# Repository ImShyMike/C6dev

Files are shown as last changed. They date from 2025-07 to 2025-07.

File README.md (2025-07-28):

# C6dev

A tiny and low power dev board for the ESP32-C6 with 10 GPIO pins, microSD card slot, 64Mbit (8MB) of Quad SPI Flash, USB C 2.0, a step-down converter for efficiency, 2.4 GHz ceramic chip antenna and very cool silkscreen. All pins are labeled with their number, actual GPIO and even other functions.

---

I've been wanting to make a devboard for a while now so i decided to make one with a RISC-V, low power MCU while breaking out a bunch of useful stuff while still keeping an acceptable amount of GPIO.

It was quite a lot harder than I expected with all the datasheet searching and looking up everything to make sure it works but atleast the routing was quite fun.

---

| PCB front | PCB back |
|:---:|:---:|
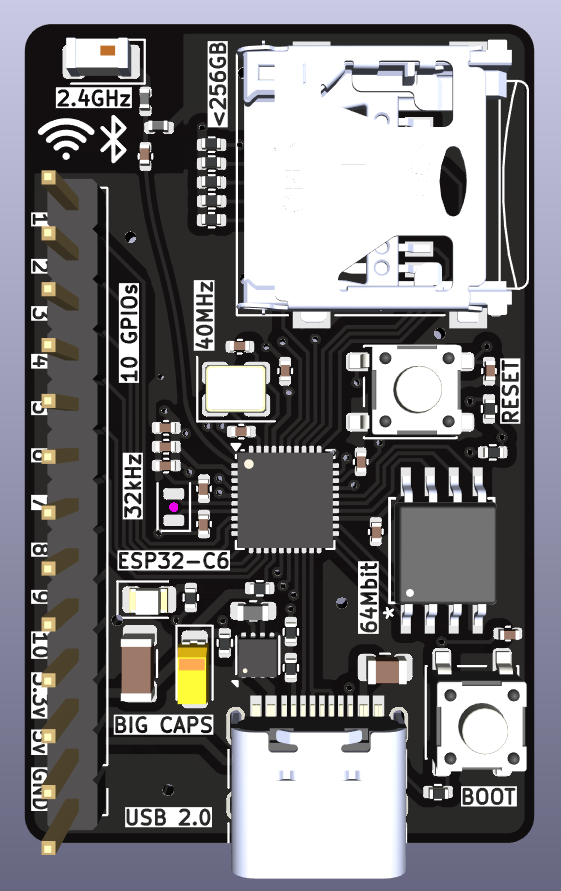
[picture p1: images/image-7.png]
PCB front
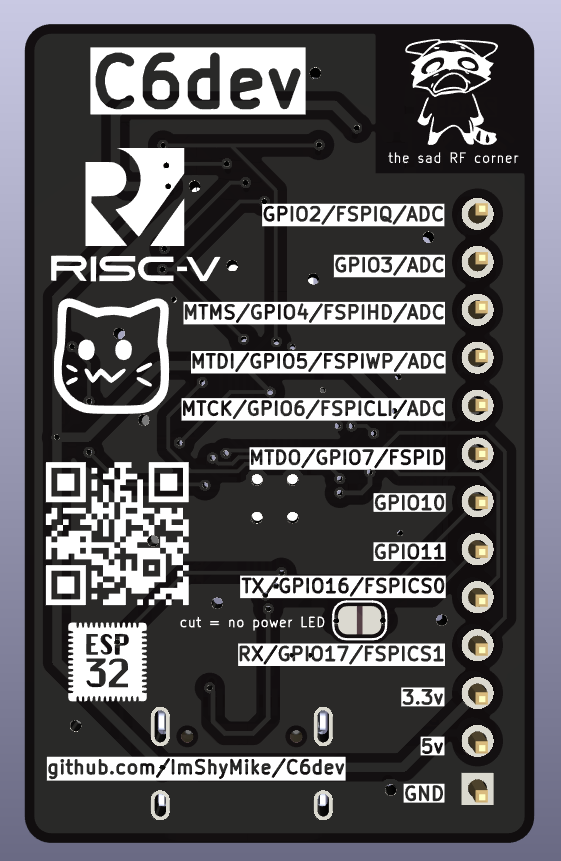
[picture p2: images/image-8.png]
PCB back
|  |  |

---

## PCB

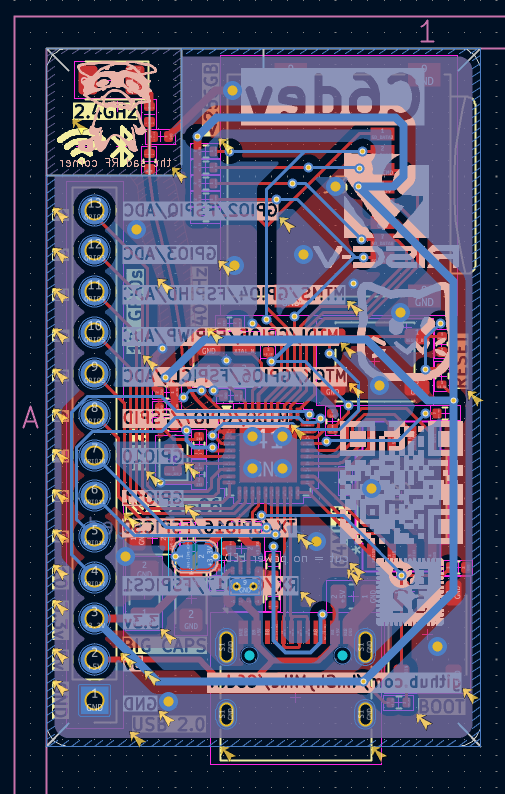
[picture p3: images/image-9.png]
PCB


---

## BOM

| Item | Quantity | Price (USD) |
|:----:|:---:|:---:|
| PCB  | 1  | $77 |

---

## 3D Model

[STL (renders on GitHub)](PCB/devboard/devboard.stl)

[STEP](PCB/devboard/devboard.stl)

[WRL (best)](PCB/devboard/devboard.wrl)

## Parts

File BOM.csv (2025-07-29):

Item | Quantity | Price (USD)
PCB | 1 | 77

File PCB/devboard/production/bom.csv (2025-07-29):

Designator | Footprint | Quantity | Value | LCSC Part #
AE1 | Johanson_2450AT18x100_2400-2500Mhz | 1 | Antenna
C1, C10, C11, C12, C15, C16, C8, C9 | 0402 | 8 | 100nF
C13 | 0402 | 1 | 1.2pF
C14 | CP_EIA-3216-18_Kemet-A | 1 | 100uF
C2, C3 | 0402 | 2 | 12pF
C4, C5 | 0402 | 2 | 6.8pF
C6 | 0805 | 1 | 10uF
C7 | 1206 | 1 | 22uF
D1 | 0805 | 1 | LED
J1 | PinHeader_1x13_P2.54mm_Vertical | 1 | Conn_01x13_Pin
J3 | microSD_HC_Wuerth_693072010801 | 1 | Micro_SD_Card
J4 | USB_C_Receptacle_HRO_TYPE-C-31-M-12 | 1 | USB_C_Receptacle_USB2.0_14P
JP1 | SolderJumper-2_P1.3mm_Open_RoundedPad1.0x1.5mm | 1 | Jumper_2_Bridged
L1 | 0603 | 1 | 2.2uH
L2 | 0402 | 1 | 3.3nH
L3 | 0402 | 1 | 2.7nH
R1, R10, R11, R12, R13, R2, R3, R4, R8, R9 | 0402 | 10 | 10k
R5, R6 | 0402 | 2 | 5.1kΩ
R7 | 0402 | 1 | 100k
SW1, SW2 | SW_SPST_PTS647_Sx38 | 2 | SW_Push
U1 | QFN-40-1EP_5x5mm_P0.4mm_EP3.6x3.6mm | 1 | ESP32-C6
U2 | WSON-8-1EP_2x2mm_P0.5mm_EP0.9x1.6mm_ThermalVias | 1 | TPS62172DSG
U3 | SOIC-8_5P28X5P28_WIN | 1 | W25Q64JVSSIQ
Y1 | Crystal_SMD_3225-4Pin_3.2x2.5mm | 1 | C521661
Y3 | Crystal_SMD_2012-2Pin_2.0x1.2mm | 1 | Crystal

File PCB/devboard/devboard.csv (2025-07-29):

Id | Designator | Footprint | Quantity | Designation | Supplier and ref
1 | U3 | SOIC-8_5P28X5P28_WIN | 1 | W25Q64JVSSIQ
2 | C15,C8,C11,C16,C9,C12,C1,C10 | C_0402_1005Metric | 8 | 100nF
3 | C14 | CP_EIA-3216-18_Kemet-A | 1 | 100uF
4 | R5,R6 | R_0402_1005Metric | 2 | 5.1kΩ
5 | C4,C5 | C_0402_1005Metric | 2 | 6.8pF
6 | C6 | C_0805_2012Metric | 1 | 10uF
7 | R8,R13,R9,R3,R4,R11,R10,R12,R1,R2 | R_0402_1005Metric | 10 | 10k
8 | SW1,SW2 | SW_SPST_PTS647_Sx38 | 2 | SW_Push
9 | J3 | microSD_HC_Wuerth_693072010801 | 1 | Micro_SD_Card
10 | L1 | L_0603_1608Metric | 1 | 2.2uH
11 | AE1 | Johanson_2450AT18x100_2400-2500Mhz | 1 | Antenna
12 | J1 | PinHeader_1x13_P2.54mm_Vertical | 1 | Conn_01x13_Pin
13 | L2 | L_0402_1005Metric | 1 | 3.3nH
14 | C7 | C_1206_3216Metric | 1 | 22uF
15 | U1 | QFN-40-1EP_5x5mm_P0.4mm_EP3.6x3.6mm | 1 | ESP32-C6
16 | C2,C3 | C_0402_1005Metric | 2 | 12pF
17 | L3 | L_0402_1005Metric | 1 | 2.7nH
18 | Y1 | Crystal_SMD_3225-4Pin_3.2x2.5mm | 1 | C521661
19 | D1 | LED_0805_2012Metric | 1 | LED
20 | U2 | WSON-8-1EP_2x2mm_P0.5mm_EP0.9x1.6mm_ThermalVias | 1 | TPS62172DSG
21 | Y3 | Crystal_SMD_2012-2Pin_2.0x1.2mm | 1 | Crystal
22 | J4 | USB_C_Receptacle_HRO_TYPE-C-31-M-12 | 1 | USB_C_Receptacle_USB2.0_14P
23 | C13 | C_0402_1005Metric | 1 | 1.2pF
24 | R7 | R_0402_1005Metric | 1 | 100k
25 | JP1 | SolderJumper-2_P1.3mm_Open_RoundedPad1.0x1.5mm | 1 | Jumper_2_Bridged

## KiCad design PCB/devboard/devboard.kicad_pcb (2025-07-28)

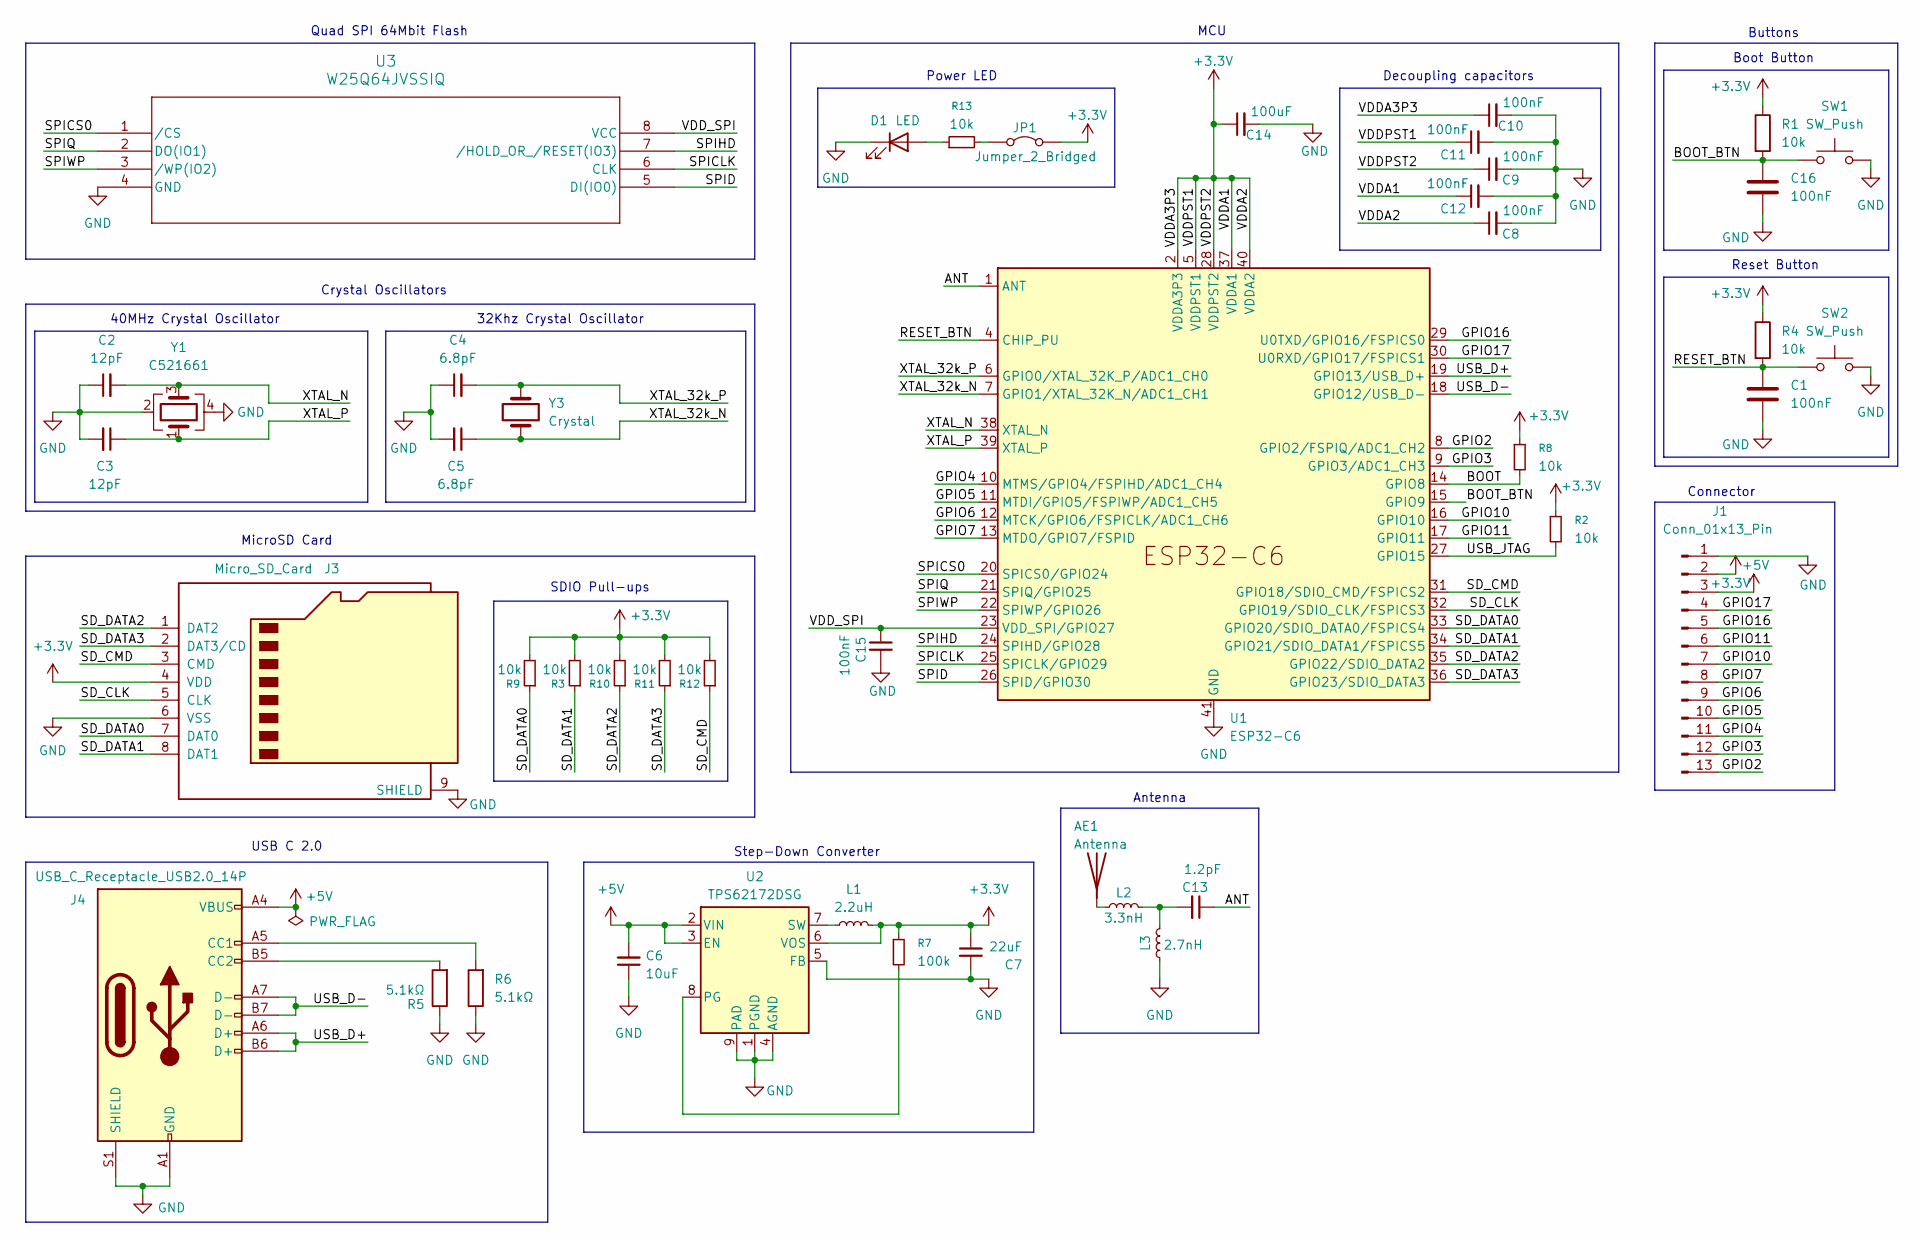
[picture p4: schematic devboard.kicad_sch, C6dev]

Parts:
AE1: Antenna; Johanson_2450AT18x100_2400-2500Mhz
C1, C8, C9, C10, C11, C12, C15, C16: 100nF; C_0402_1005Metric
C2, C3: 12pF; C_0402_1005Metric
C4, C5: 6.8pF; C_0402_1005Metric
C6: 10uF; C_0805_2012Metric
C7: 22uF; C_1206_3216Metric
C13: 1.2pF; C_0402_1005Metric
C14: 100uF; CP_EIA-3216-18_Kemet-A
D1: LED; LED_0805_2012Metric
J1: Conn_01x13_Pin; PinHeader_1x13_P2.54mm_Vertical
J3: Micro_SD_Card; microSD_HC_Wuerth_693072010801
J4: USB_C_Receptacle_USB2.0_14P; USB_C_Receptacle_HRO_TYPE-C-31-M-12
JP1: Jumper_2_Bridged; SolderJumper-2_P1.3mm_Open_RoundedPad1.0x1.5mm
L1: 2.2uH; L_0603_1608Metric
L2: 3.3nH; L_0402_1005Metric
L3: 2.7nH; L_0402_1005Metric
R1, R2, R3, R4, R8, R9, R10, R11, R12, R13: 10k; R_0402_1005Metric
R5, R6: 5.1kΩ; R_0402_1005Metric
R7: 100k; R_0402_1005Metric
SW1, SW2: SW_Push; SW_SPST_PTS647_Sx38
U1: ESP32-C6; QFN-40-1EP_5x5mm_P0.4mm_EP3.6x3.6mm
U2: TPS62172DSG; WSON-8-1EP_2x2mm_P0.5mm_EP0.9x1.6mm_ThermalVias
U3: W25Q64JVSSIQ; SOIC-8_5P28X5P28_WIN
Y1: C521661; Crystal_SMD_3225-4Pin_3.2x2.5mm
Y3: Crystal; Crystal_SMD_2012-2Pin_2.0x1.2mm

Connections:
+3.3V: C7.1, C8.1, C9.1, C10.1, C11.1, C12.1, C14.1, J1.3, J3.4 (VDD), JP1.2 (B), L1.2, R1.1, R2.1, R3.2, R4.1, R7.1, R8.1, R9.2, R10.2, R11.2, R12.2, U1.2 (VDDA3P3), U1.3 (VDDA3P3), U1.5 (VDDPST1), U1.28 (VDDPST2), U1.37 (VDDA1), U1.40 (VDDA2), U2.6 (VOS)
+5V: C6.2, J1.2, J4.A4 (VBUS), J4.A9 (VBUS), J4.B4 (VBUS), J4.B9 (VBUS), U2.2 (VIN), U2.3 (EN)
/ANT: C13.1, U1.1 (ANT)
/BOOT: R8.2, U1.14 (GPIO8)
/BOOT_BTN: C16.1, R1.2, SW1.1, U1.15 (GPIO9)
/GPIO2: J1.13, U1.8 (GPIO2/FSPIQ/ADC1_CH2)
/GPIO3: J1.12, U1.9 (GPIO3/ADC1_CH3)
/GPIO4: J1.11, U1.10 (MTMS/GPIO4/FSPIHD/ADC1_CH4)
/GPIO5: J1.10, U1.11 (MTDI/GPIO5/FSPIWP/ADC1_CH5)
/GPIO6: J1.9, U1.12 (MTCK/GPIO6/FSPICLK/ADC1_CH6)
/GPIO7: J1.8, U1.13 (MTDO/GPIO7/FSPID)
/GPIO10: J1.7, U1.16 (GPIO10)
/GPIO11: J1.6, U1.17 (GPIO11)
/GPIO16: J1.5, U1.29 (U0TXD/GPIO16/FSPICS0)
/GPIO17: J1.4, U1.30 (U0RXD/GPIO17/FSPICS1)
/RESET_BTN: C1.1, R4.2, SW2.1, U1.4 (CHIP_PU)
/SD_CLK: J3.5 (CLK), U1.32 (GPIO19/SDIO_CLK/FSPICS3)
/SD_CMD: J3.3 (CMD), R12.1, U1.31 (GPIO18/SDIO_CMD/FSPICS2)
/SD_DATA0: J3.7 (DAT0), R9.1, U1.33 (GPIO20/SDIO_DATA0/FSPICS4)
/SD_DATA1: J3.8 (DAT1), R3.1, U1.34 (GPIO21/SDIO_DATA1/FSPICS5)
/SD_DATA2: J3.1 (DAT2), R10.1, U1.35 (GPIO22/SDIO_DATA2)
/SD_DATA3: J3.2 (DAT3/CD), R11.1, U1.36 (GPIO23/SDIO_DATA3)
/SPICLK: U1.25 (SPICLK/GPIO29), U3.6 (CLK)
/SPICS0: U1.20 (SPICS0/GPIO24), U3.1 (/CS)
/SPID: U1.26 (SPID/GPIO30), U3.5 (DI(IO0))
/SPIHD: U1.24 (SPIHD/GPIO28), U3.7 (/HOLD_OR_/RESET(IO3))
/SPIQ: U1.21 (SPIQ/GPIO25), U3.2 (DO(IO1))
/SPIWP: U1.22 (SPIWP/GPIO26), U3.3 (/WP(IO2))
/USB_D+: J4.A6 (D+), J4.B6 (D+), U1.19 (GPIO13/USB_D+)
/USB_D-: J4.A7 (D-), J4.B7 (D-), U1.18 (GPIO12/USB_D-)
/USB_JTAG: R2.2, U1.27 (GPIO15)
/VDD_SPI: C15.1, U1.23 (VDD_SPI/GPIO27), U3.8 (VCC)
/XTAL_32k_N: C5.1, U1.7 (GPIO1/XTAL_32K_N/ADC1_CH1), Y3.1
/XTAL_32k_P: C4.2, U1.6 (GPIO0/XTAL_32K_P/ADC1_CH0), Y3.2
/XTAL_N: C2.2, U1.38 (XTAL_N), Y1.3
/XTAL_P: C3.1, U1.39 (XTAL_P), Y1.1
GND: C1.2, C2.1, C3.2, C4.1, C5.2, C6.1, C7.2, C8.2, C9.2, C10.2, C11.2, C12.2, C14.2, C15.2, C16.2, D1.1 (K), J1.1, J3.6 (VSS), J3.9 (SHIELD), J4.A1 (GND), J4.A12 (GND), J4.B1 (GND), J4.B12 (GND), J4.S1 (SHIELD), L3.1, R5.1, R6.1, SW1.2, SW2.2, U1.41 (GND), U2.1 (PGND), U2.4 (AGND), U2.5 (FB), U2.9 (PAD), U3.4 (GND), Y1.2, Y1.4
unnamed: AE1.1 (A), L2.1
unnamed: C13.2, L2.2, L3.2
unnamed: D1.2 (A), R13.1
unnamed: J4.A5 (CC1), R6.2
unnamed: J4.B5 (CC2), R5.2
unnamed: JP1.1 (A), R13.2
unnamed: R7.2, U2.8 (PG)
unnamed: L1.1, U2.7 (SW)

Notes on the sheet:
40MHz Crystal Oscillator
MCU
Buttons
USB C 2.0
Connector
Power LED
Decoupling capacitors
32Khz Crystal Oscillator
Crystal Oscillators
Boot Button
Step-Down Converter
Reset Button
Antenna
MicroSD Card
SDIO Pull-ups
Quad SPI 64Mbit Flash

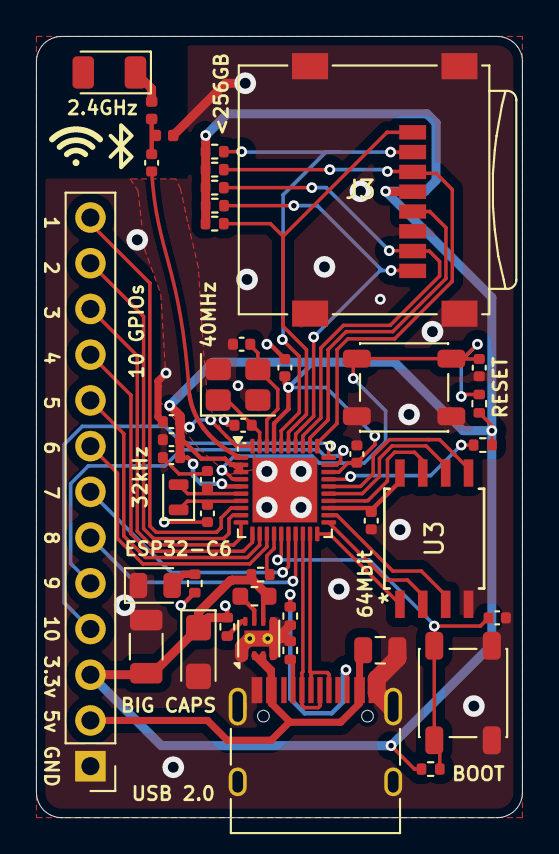
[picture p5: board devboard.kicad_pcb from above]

Board: 2 copper layers, 27.0 x 43.4 mm, 45 parts (1 on the bottom side), 45 nets.

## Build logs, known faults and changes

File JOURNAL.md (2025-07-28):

---
title: "C6dev"
author: "ShyMike"
description: "A tiny and low power dev board for the ESP32-C6"
created_at: "2025-07-26"
---

## Total time: 19 hours

---

# July 26th: Started researching

Started looking for and reasearching a bunch of chips from Expressif and STMicroelectronics

Most interesting ones:

- ESP32-S3
- ESP32-C3
- ESP32-C6
- STM32F407
- STM32F746

**Total time spent: 1h**

---

# July 26th pt2: Made a choice and started designing the schematic

I ended up choosing the ESP32-C6 for it's low power consumption, speed, relatively low complexity and availability

- [ESP-32-C6](https://jlcpcb.com/partdetail/EspressifSystems-ESP32C6/C5364646)

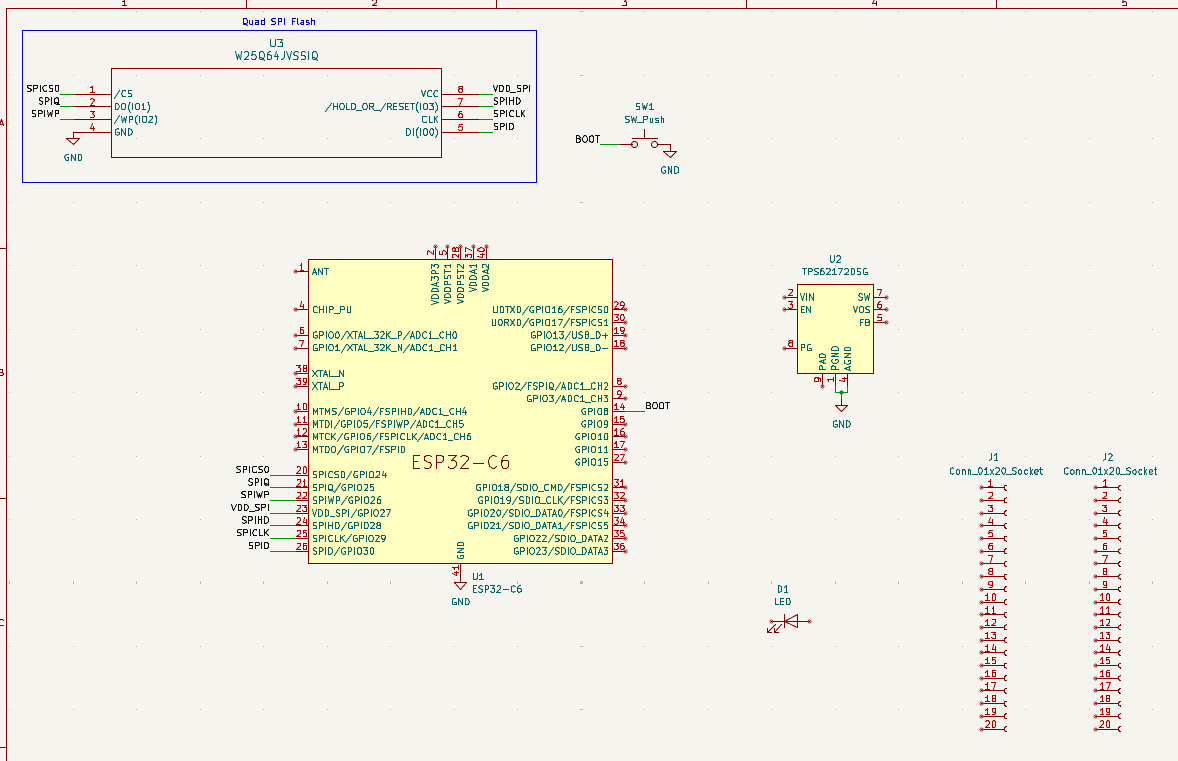
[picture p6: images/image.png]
Starting schematic


**Total time spent: 1h**

---

# July 26th pt3: More schematic making :sob:

Tried to actually use net labels propperly and follow best practices while keeping the schematic clean and already have a 5v to 3.3v step down, crystals, flash, usb c, boot/reset buttons and a microSD.

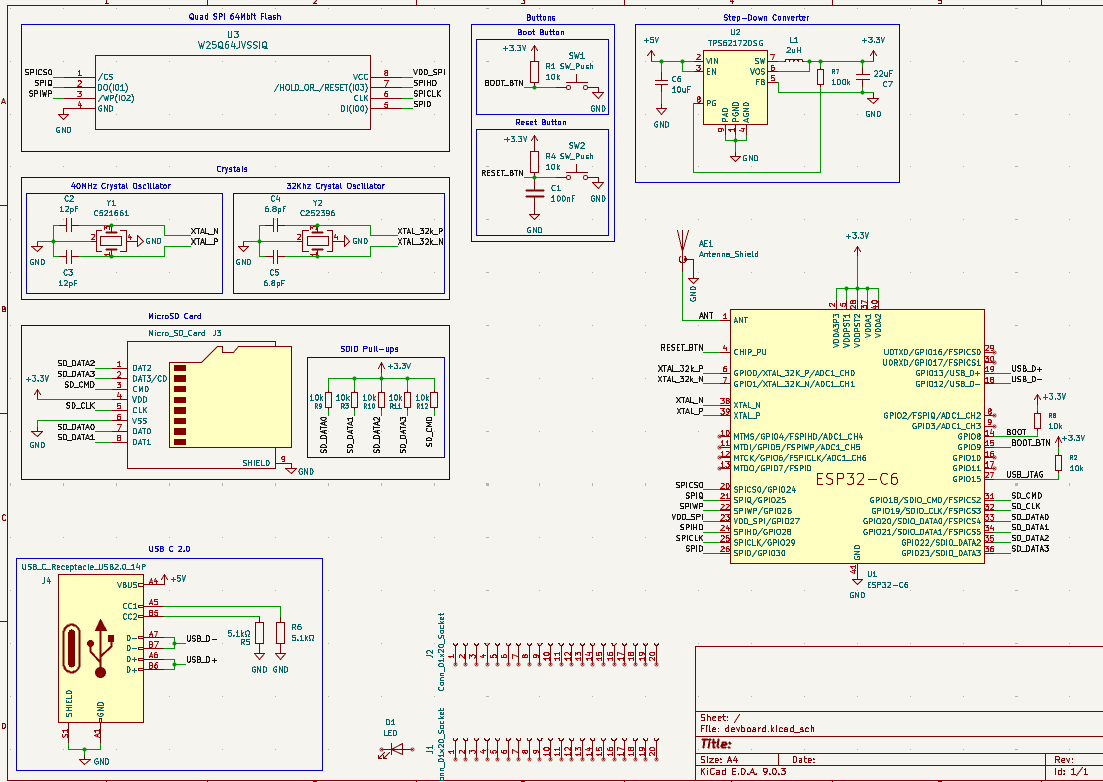
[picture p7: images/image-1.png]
Schematic looking decent


Schematicsssss

- https://jlcpcb.com/api/file/downloadByFileSystemAccessId/8588949628351471616
- https://jlcpcb.com/api/file/downloadByFileSystemAccessId/8588881904569356288
- https://www.espressif.com/sites/default/files/documentation/esp32-c6_datasheet_en.pdf

**Total time spent: 3h**

---

# July 26th pt4: Finishing up the schematic

Should be finished with the schematic will double check everything for errors and start the with the PCB

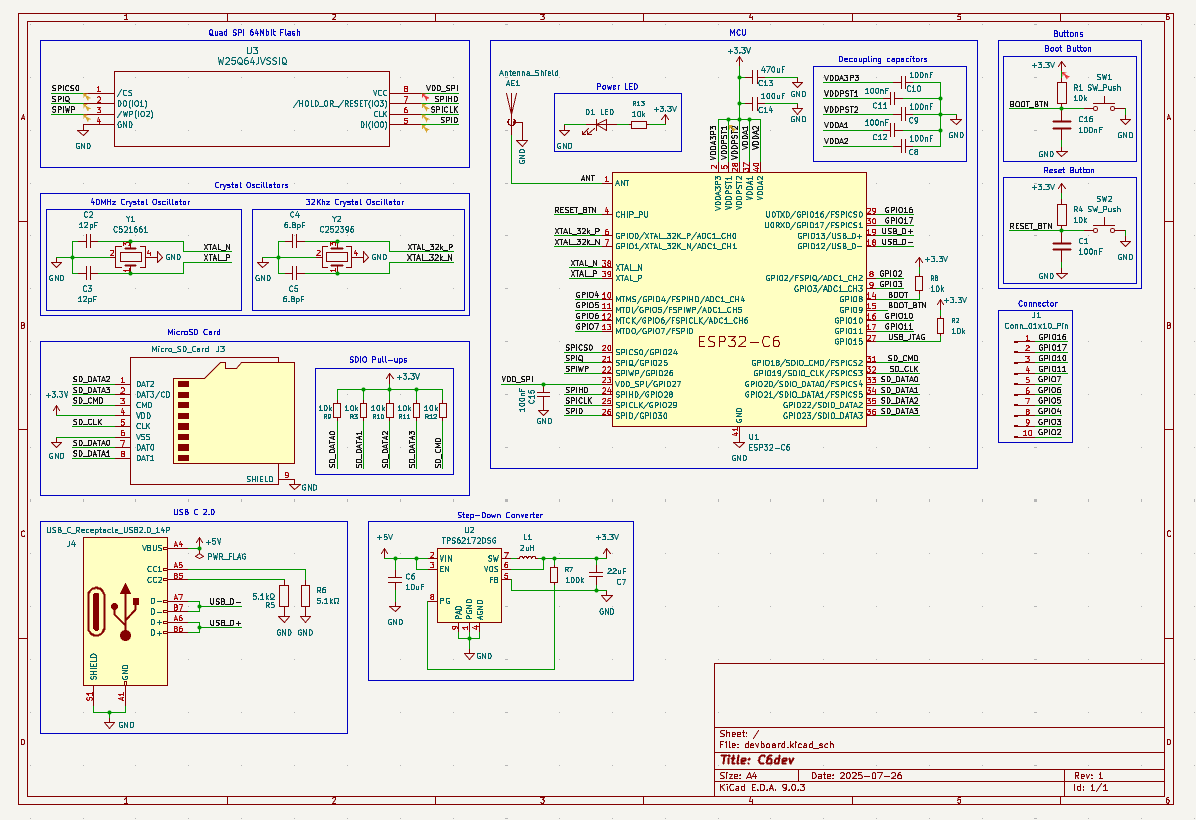
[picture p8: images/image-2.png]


**Total time spent: 2h**

---

# July 27th: PCB done (i think)

> KiCad autosave is the best thing ever made by humanity

I thought that i had lost almost 2 hours of work but thankfully autosave saved me (don't ask why i didn't save for 2 hours, i don't know either)

After a lot of pain and suffering, and forgetting to place the pullups on the SDIO lines, the PCB is mostly finished and only needs some finishing touches

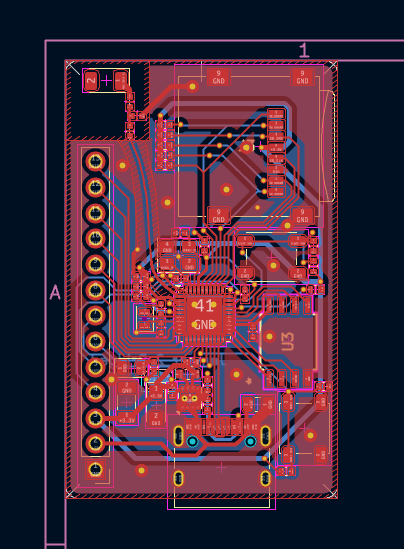
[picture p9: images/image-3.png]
Finished PCB


<sub>im about 1% confident that the antenna will work</sub>

Also fixed some minor issues with the schematic

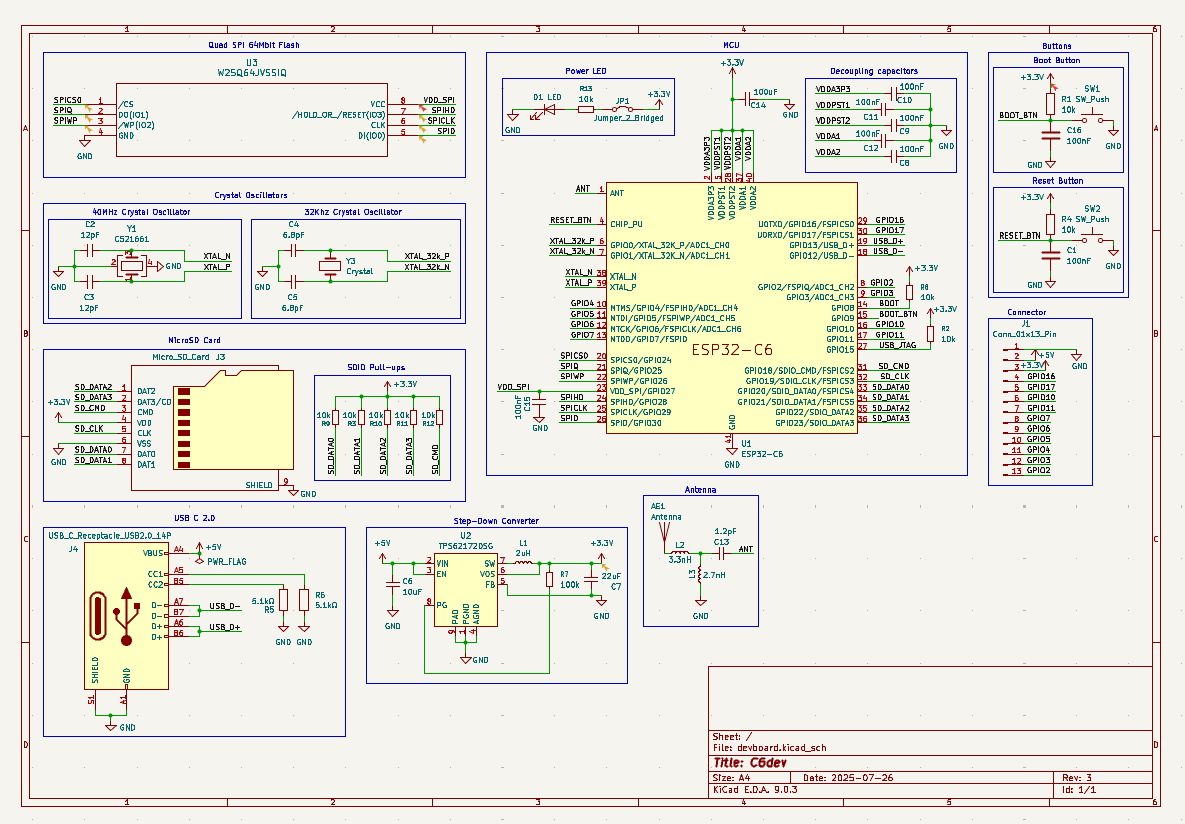
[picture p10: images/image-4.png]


[i love RF i love RF i love RF](https://jlcpcb.com/api/file/downloadByFileSystemAccessId/8588940948130156544)

**Total time spent: 6h**

---

# July 27th pt2: Polishing

Polishing tiny details on the PCb and adding silkscreen as well as checking prices

**Total time spent: 1h**

---

# July 27th pt2: SILKSCREEEEEEN

PCB was looking extremely boring so ofc i had to spend copious amounts of time adding silkscreen art :3

(it's still not done, i need MORE)

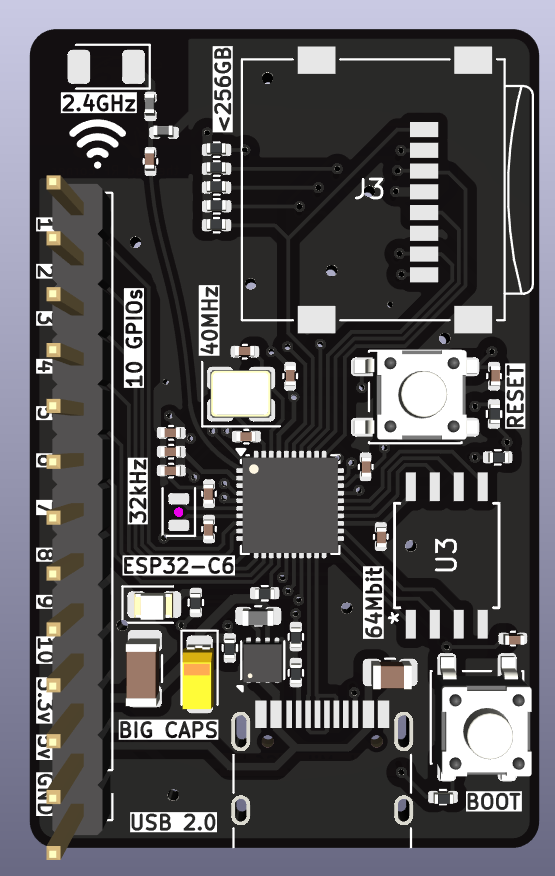
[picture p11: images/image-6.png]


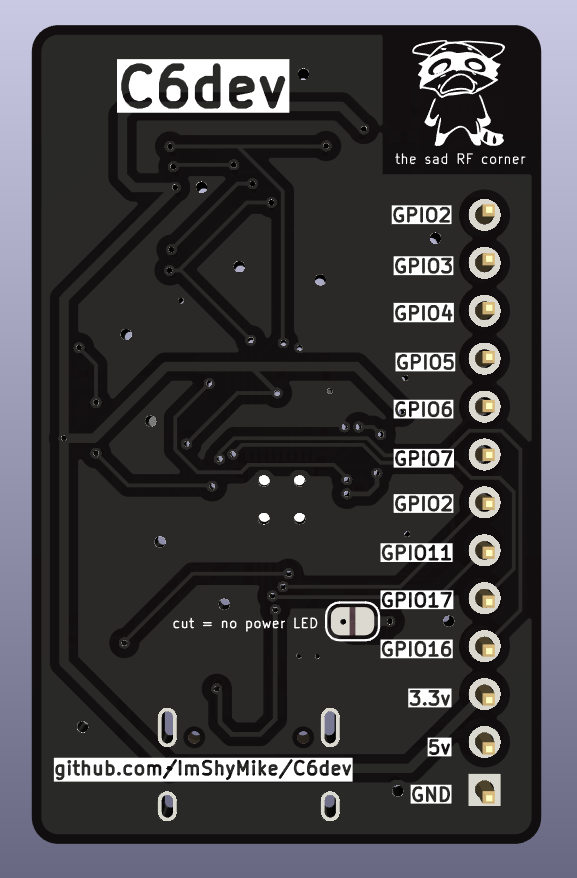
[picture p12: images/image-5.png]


The back is still quite empty and that will be dealt with later

**Total time spent: 2h**

---

# July 28th: A lot of polish :3

Got all od the missing 3D models to make a cool PCB image and added a bunch of helpful and fun silkscreen stuff

PCB front

PCB back

The state of the PCB now :sob:

PCB

**Total time spent: 2h**

---

# July 28th: README stuffs

Finished the README and BOM and double checked if im missing anything

**Total time spent: 1h**

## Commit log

2025-07-26 start schematic
    [devboard.kicad_pcb, devboard.kicad_sch]
2025-07-26 finished schematic
    [devboard.kicad_sch]
2025-07-27 pcb done :yay:
    [devboard.kicad_pcb, devboard.kicad_sch]
2025-07-27 move the pcb to the corner
    [devboard.kicad_pcb]
2025-07-27 adjust ant trace
    [devboard.kicad_pcb]
2025-07-27 export pcb
    [devboard.kicad_pcb]
2025-07-28 finishing up
    [devboard.kicad_pcb, devboard.kicad_sch]
2025-07-28 smaller stl
